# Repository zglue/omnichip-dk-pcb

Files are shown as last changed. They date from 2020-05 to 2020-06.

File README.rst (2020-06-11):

OmniChip Development Board PCB Design Files
*******************************************

.. _figure_ftdi_drivers:
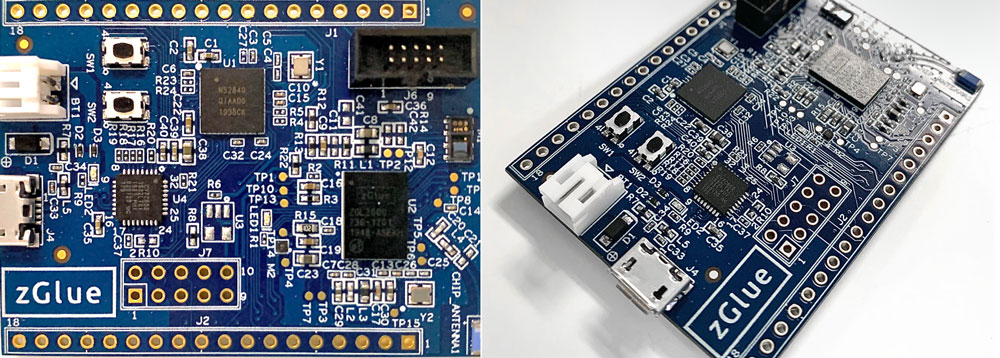
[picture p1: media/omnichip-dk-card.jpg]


Version: 1.0.0

Author(s): Jorge L. Rojas, Olivia Liao

zGlue Inc, 883 N Shoreline Blvd, C200, Mountain View, CA 94043, USA

Contact(s): jorge@zglue.com, olivia@zglue.com

*Released under zOH License v. 1.0 for open-source development*

Overview
========

`Click here to purchase an OmniChip development board <https://zglue.com/products/omnichip>`_

Want to explore zGlue's technology? Get familiar with the first active silicon interposer with the OmniChip development board. OmniChip is a full system on a chip built with this technology including: a Cortex-M4 MCU + BLE, a battery charger, a heart rate sensor, 3-axis accelerometer, 3-axis magnetometer, a temperature sensor, and a 32kHz TCXO. The hardware design files found in this repository are being released by zGlue Inc under the zGlue Open Hardware V1 license.

Make an account on zGlue's `ChipBuilder web tool <https://zglue.com/products/chipbuilder>`_, and visit the `OmniChip system design <https://chipbuilder.zglue.com/system/2647/physical/>`_ to modify the OmniChip design. With hardware at your fingertips, you can start programming your ZIP!

What's Included?
================

* OmniChip DK schematic design files
* OmniChip DK layout & gerber files
* zGlue Open Hardware License V1 (zOH V1 License)

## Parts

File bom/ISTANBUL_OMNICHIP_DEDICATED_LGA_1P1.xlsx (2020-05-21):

Item | Quantity | Quantity needed | Quantity ordered | Reference | Part | PCB Footprint | Manufacturer | Part Number | Distributor | Distributor Part Number
1 | 1 | 50 | 55 | BT1 | JST-2PIN-MALE | HDR1X2X2MM_S2B-PH-K-S | JST Sales America Inc. | S2B-PH-K-S(LF)(SN) | Digikey | 455-1719-ND
2 | 1 | 50 | 60 | CHIP_ANTENNA1 | A0 | RFANT3216120A5T | Walsin Technology Corporation | RFANT3216120A5T | Digikey | 1292-1000-1-ND
3 | 6 | 300 | 500 | C1,C2,C12,C17,C35,C36 | 1 uF | 402 | Samsung Electro-Mechanics | CL05A105MP5NNNC | Digikey | 1276-1448-1-ND
4 | 9 | 450 | 600 | C3,C6,C7,C18,C24,C28,C31,C32,C34 | 0.1 uF | 201 | Murata Electronics | GRM033R61A104ME15D | DigiKey | 490-5405-1-ND
5 | 4 | 200 | 300 | C4,C5,C25,C26 | 8 pF | 201 | Murata Electronics | GRM0335C1H8R0DA01J | DigiKey | 490-13331-1-ND
6 | 3 | 150 | 250 | C8,C23,C38 | 10 uF | 603 | Taiyo Yuden | LMK107BBJ106MALT | DigiKey | 587-3258-1-ND
7 | 4 | 200 | 300 | C9,C16,C19,C22 | 4.7 uF | 402 | Murata Electronics | GRM155R61A475MEAAD | DigiKey | 490-14306-1-ND
8 | 3 | 150 | 250 | C10,C13,C14 | 0.1 nF | 201 | Murata Electronics | GRM033R71C101KA01D | DigiKey | 490-6146-1-ND
9 | 1 |  |  | C11 | DNP | 402
10 | 1 | 50 | 100 | C15 | 820 pF | 201 | Murata Electronics | GRM033R71E821KA01D | DigiKey | 490-3183-1-ND
11 | 1 | 50 | 100 | C20 | 0.8pF | 402 | Walsin Technology Corporation | 0402N0R8B500CT | Digikey | 1292-1236-1-ND
12 | 1 | - | - | C21 | DNP | 402
13 | 1 | - | - | C27 | DNP | 201
14 | 3 | 150 | 200 | C29,C30,C40 | 2.2 uF | 402 | Taiyo Yuden | LMK105BJ225MV-F | DigiKey | 587-3153-1-ND
15 | 1 | 50 | 100 | C33 | 10 nF | 201 | Murata Electronics | GRM033R71E103KE14D | DigiKey | 490-14454-1-ND
16 | 1 | - | - | C37 | DNP | 201
17 | 1 | 50 | 100 | C39 | 0.1 uF | 402 | Taiyo Yuden | EMK105BJ105KV-F | DigiKey | 587-2477-1-ND
18 | 1 | - | - | C41 | DNP | 603
19 | 1 | - | - | C42 | DNP | 402
20 | 1 | 50 | 100 | D1 | MMSZ5231B-7-F | SOD123 | Diodes Incorporated | MMSZ5231B-7-F | Digikey | MMSZ5231B-FDICT-ND
21 | 2 | 100 | 150 | D2,D3 | PDIODE | SOD923 | ON Semiconductor | NSR0620P2T5G | Digikey | NSR0620P2T5GOSCT-ND
22 | 2 | 100 |  | J1,J2 | DNP |  | Adam Tech | PH1-12-UA | Digikey
23 | 1 | 50 | 55 | J4 | USB MICRO | usb_micro-b | Amphenol FCI | 10118193-0001LF | Digikey | 609-4616-1-ND
24 | 1 | 50 | 55 | J6 | HDR 5x2 | CNC_3220-10-0100-00 | CNC Tech |  | Digikey | 1175-1627-ND
25 | 1 | - | - | J7 | DNP
26 | 2 | 100 | 150 | LED1,LED2 | RED | sml-p12-p13x | Rohm Semiconductor | SML-P12U2TT86R | Digikey | 846-1192-1-ND
27 | 1 | 50 | 100 | L1 | 2.2 uH | 603 | TDK Corporation | MLZ1608N2R2LT000 | Digikey | 445-6754-1-ND
28 | 1 | 50 | 100 | L2 | 15 nH | 402 | Taiyo Yuden | HK100515NJ-T | Digikey | 587-1521-1-ND
29 | 1 | 50 | 100 | L3 | 10 uH | 603 | TDK Corporation | MLZ1608N100LT000 | Digikey | 445-6755-1-ND
30 | 1 | 50 | 100 | L4 | 3.9 nH | 402 | Taiyo Yuden | HK10053N9S-T | Digikey | 587-1509-1-ND
31 | 1 | 50 | 100 | L5 | 120R/0.55A | 402 | TDK Corporation | MMZ1005S121CT000‎ | Digikey | 445-2160-1-ND‎
32 | 1 | 50 | 55 | M1 | SFH7050 | SFH_7050 | OSRAM Opto Semiconductors Inc. | SFH 7050 | Digikey | 475-3346-1-ND
33 | 1 | 50 | 100 | M2 | UHD1110-FKA-CL1A13R3Q1BBQFMF3 |  | Cree Inc. | UHD1110-FKA-CL1A13R3Q1BBQFMF3 | Digikey | UHD1110-FKA-CL1A13R3Q1BBQFMF3CT-ND
34 | 2 | 100 | 150 | R1,R9 | 402 | 201 | Yageo | RC0201FR-07402RL | Digikey | YAG2658CT-ND
35 | 3 | - | - | R2,R23,R24 | DNP | 201
36 | 2 | 100 | 150 | R3,R8 | 1000 | 402 | Yageo | RC0402FR-071KL | Digikey | 311-1.00KLRCT-ND
37 | 2 | - | - | R4,R5 | DNP | 201
38 | 1 | 50 | 100 | R6 | 499k | 201 | Yageo | ?RC0201FR-07499KL? | Digikey | ?YAG2699CT-ND?
39 | 3 | 150 | 250 | R7,R11,R22 | 0 | 402 | Yageo | RC0402JR-070RL | Digikey | 311-0.0JRCT-ND
40 | 1 | - | - | R10 | DNP | 402
41 | 1 | 50 | 100 | R12 | 14.3K | 402 | Panasonic Electronic Components | ERJ-2RKF1432X | Digikey | P14.3KLCT-ND
42 | 1 | 50 | 100 | R13 | 14K | 402 | Yageo | RC0402FR-0714KL | Digikey | 311-14.0KLRCT-ND
43 | 1 | - | - | R14 | DNP | 402
44 | 1 | 50 | 100 | R15 | 1000 | 603 | Yageo | RC0603JR-071KL | Digikey | 311-1.0KGRCT-ND
45 | 6 | 300 | 400 | R16,R17,R18,R19,R20,R21 | 22 | 201 | Stackpole Electronics Inc | RMCF0201FT22R0 | Digikey | RMCF0201FT22R0CT-ND
46 | 2 | 100 | 110 | SW1,SW2 | KMR221GLFS |  | C&K | KMR221GLFS | Digikey | 401-1427-6-ND
47 | 15 | 750 |  | TP1,TP2,TP3,TP4,TP5,TP6,TP7,TP8,TP9,TP10,TP11,TP12,TP13,TP14,TP15 | TP_MINITURE | tp_smd35r
48 | 1 | 50 | 55 | U1 | NRF52840 | AQFN73_7x7mm_p5mm_ep | Nordic | NRF52840-QIAA-R | DigiKey | 1490-1071-1-ND
49 | 1 | 50 |  | U2 | OmniChip
50 | 1 | 50 | 55 | U3 | DNP
51 | 1 | 50 | 55 | U4 | CY7C65215 |  | Cypress | CY7C65215-32LTXI | Digikey | CY7C65215-32LTXI-ND
52 | 2 | 100 | 110 | Y1,Y2 | Crystal | xtal_2mmx1p6mm | EPSON | FA-128 32.0000MF10Z-AJ3 | Mouser | 732-FA12832.F10Z-AJ3

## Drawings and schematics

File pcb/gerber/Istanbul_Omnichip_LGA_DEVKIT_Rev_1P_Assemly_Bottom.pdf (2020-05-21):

# ART FILM - ASSY-BOT

# LAYER:ASSEMBLY BOTTOM

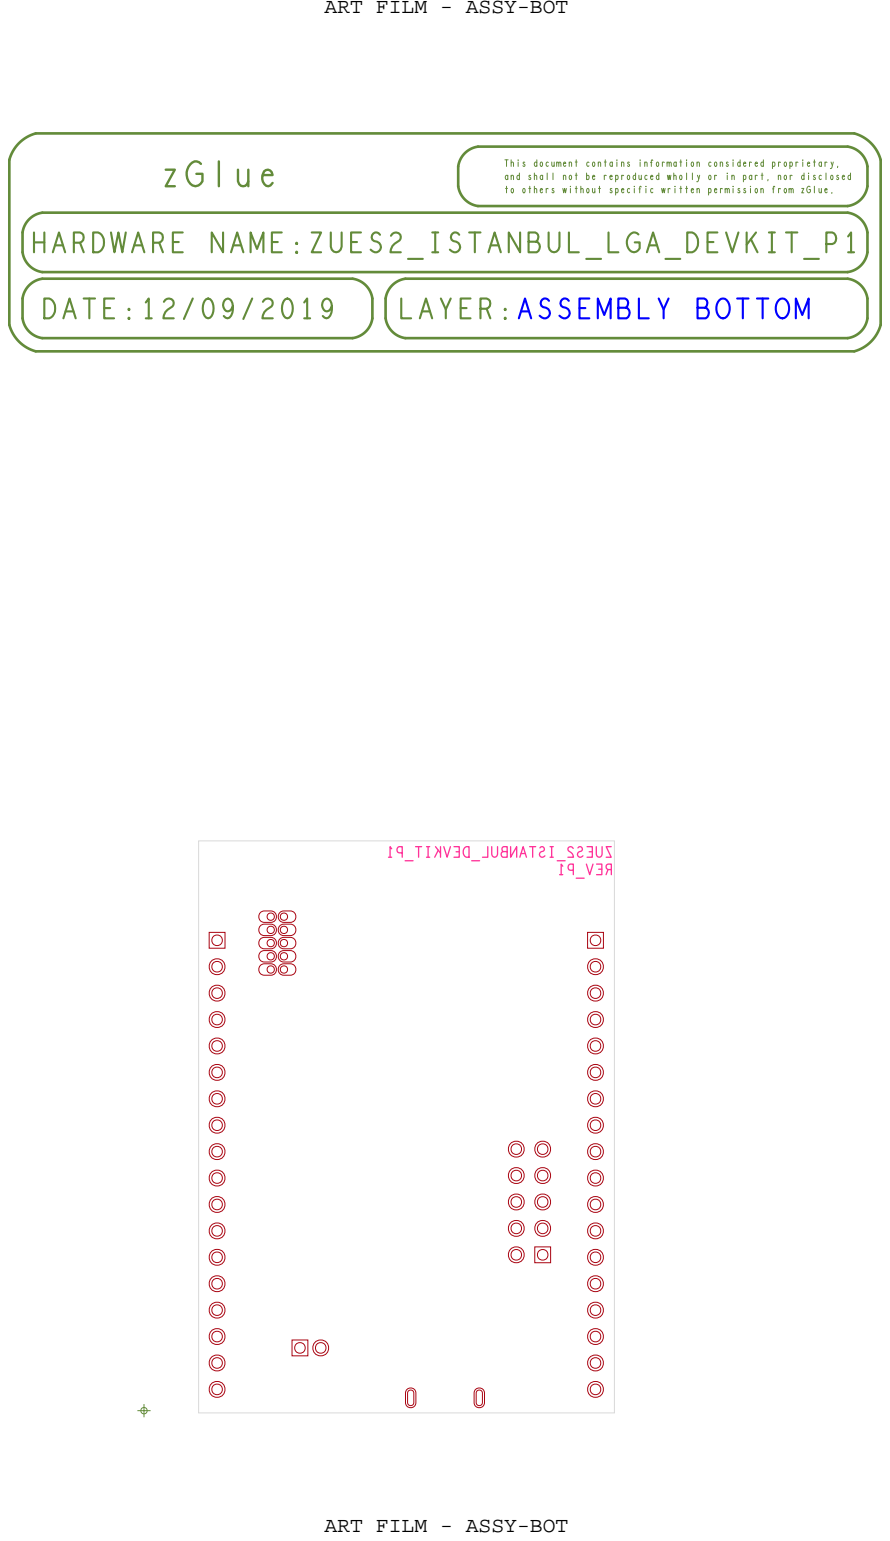
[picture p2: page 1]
zGlue; HARDWARE NAME:ZUES2_ISTANBUL_LGA_DEVKIT_P1; DATE:12/09/2019

This document contains information considered proprietary,
and shall not be reproduced wholly or in part, nor disclosed
to others without specific written permission from zGlue.

ART FILM - ASSY-BOT

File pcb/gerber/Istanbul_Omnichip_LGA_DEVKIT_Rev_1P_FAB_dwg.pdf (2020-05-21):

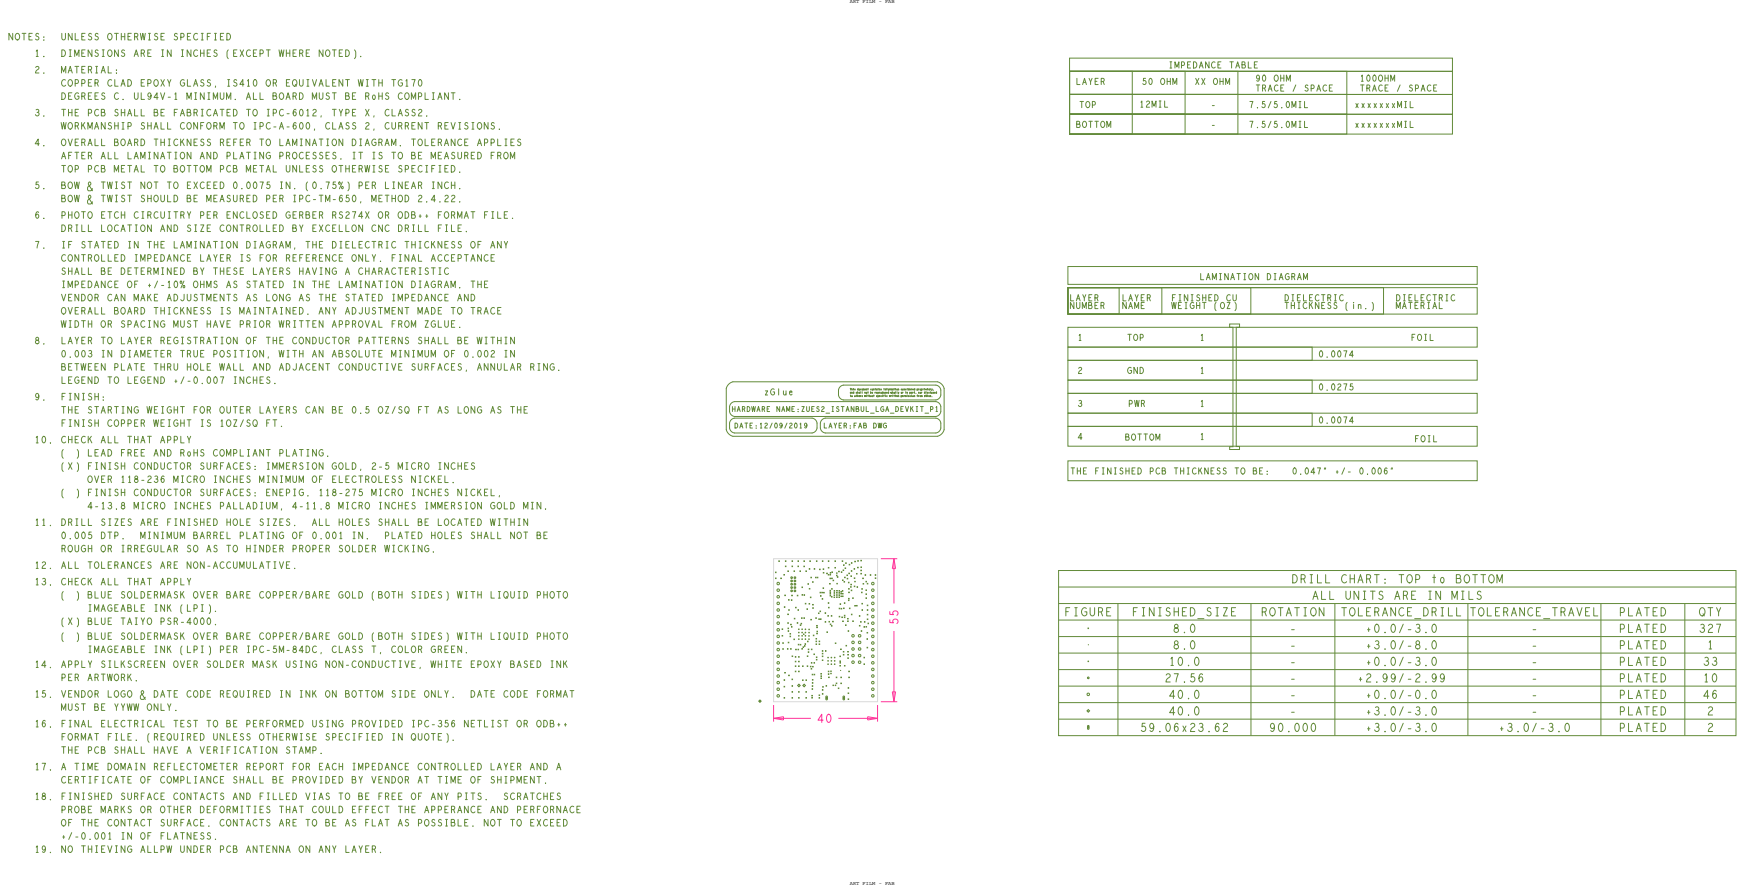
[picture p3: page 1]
QTY; PLATED; TOLERANCE_TRAVEL; MATERIAL; DIELECTRIC; FOIL; TRACE / SPACE; 100OHM; xxxxxxxMIL; 90 OHM; 7.5/5.0MIL; THICKNESS (in.); ROTATION; 50 OHM; IMPEDANCE TABLE; XX OHM; 12MIL; WEIGHT (OZ); FINISHED CU; LAMINATION DIAGRAM; FINISHED_SIZE; LAYER; BOTTOM; TOP; NUMBER; NAME; PWR; GND; THE FINISHED PCB THICKNESS; FIGURE; zGlue; HARDWARE NAME:ZUES2_ISTANBUL_LGA_DEVKIT_P1; DATE:12/09/2019; 1. DIMENSIONS ARE IN; INCHES (EXCEPT WHERE NOTED).; COPPER CLAD EPOXY GLASS,; IS410 OR EQUIVALENT WITH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

ART FILM - FAB

NOTES: UNLESS OTHERWISE SPECIFIED
2. MATERIAL:
DEGREES C. UL94V-1 MINIMUM. ALL BOARD MUST BE RoHS COMPLIANT.
6. PHOTO ETCH CIRCUITRY PER ENCLOSED GERBER RS274X OR ODB++ FORMAT FILE.
DRILL LOCATION AND SIZE CONTROLLED BY EXCELLON CNC DRILL FILE.
LEGEND TO LEGEND +/-0.007 INCHES.
9. FINISH:

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

FINISH COPPER WEIGHT IS 1OZ/SQ FT.
10. CHECK ALL THAT APPLY
( ) LEAD FREE AND RoHS COMPLIANT PLATING.

LAYER:FAB DWG

12. ALL TOLERANCES ARE NON-ACCUMULATIVE.
13. CHECK ALL THAT APPLY
IMAGEABLE INK (LPI).
(X) BLUE TAIYO PSR-4000.

DRILL CHART: TOP to BOTTOM
ALL UNITS ARE IN MILS
TOLERANCE_DRILL

PER ARTWORK.
MUST BE YYWW ONLY.
PROBE MARKS OR OTHER DEFORMITIES THAT COULD EFFECT THE APPERANCE AND PERFORNACE
+/-0.001 IN OF FLATNESS.
19. NO THIEVING ALLPW UNDER PCB ANTENNA ON ANY LAYER.

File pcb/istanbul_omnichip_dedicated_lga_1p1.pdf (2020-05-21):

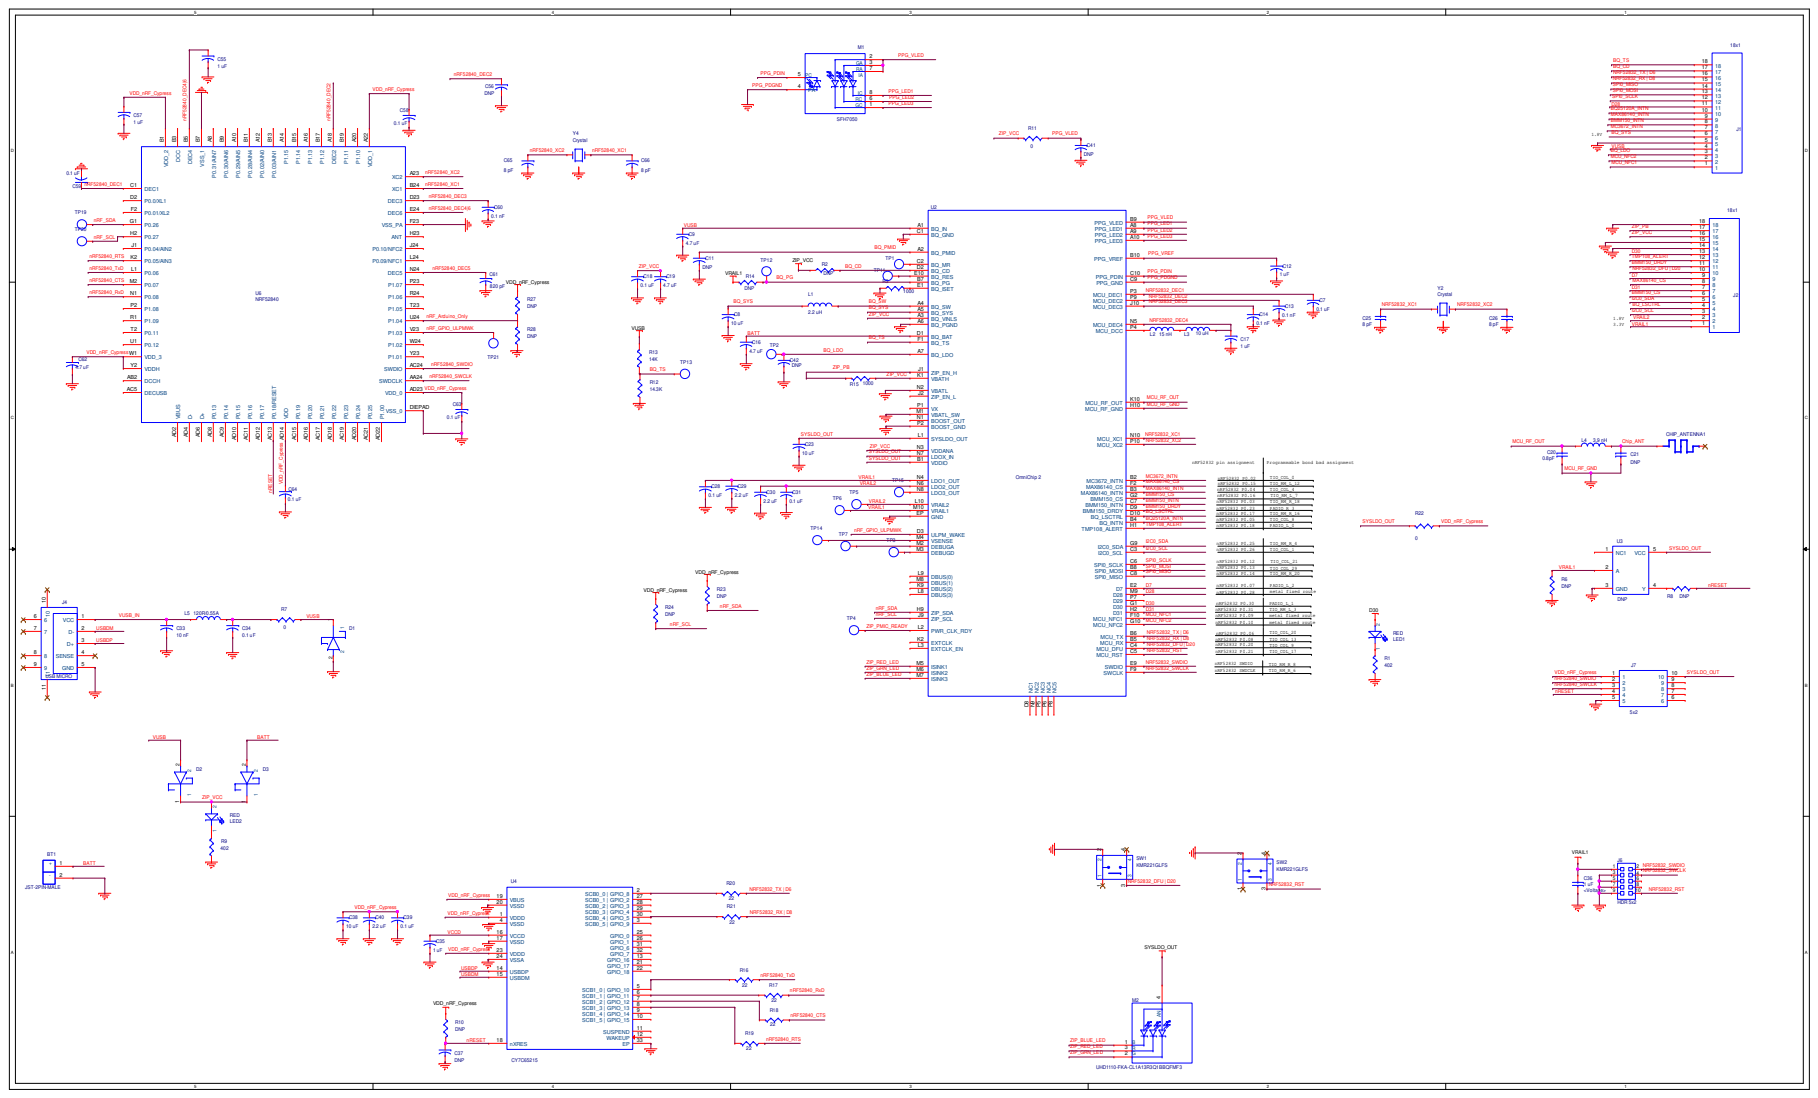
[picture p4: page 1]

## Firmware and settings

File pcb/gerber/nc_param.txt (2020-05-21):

INTEGER-PLACES         2
DECIMAL-PLACES         5
X-OFFSET               0.000000
Y-OFFSET               0.000000
FEEDRATE               1
COORDINATES            ABSOLUTE
OUTPUT-UNITS           ENGLISH
TOOL-ORDER             INCREASING
REPEAT-CODES           YES
SUPPRESS-LEAD-ZEROES   NO
SUPPRESS-TRAIL-ZEROES  NO
SUPPRESS-EQUAL         NO
TOOL-SELECT            NO
OPTIMIZE_DRILLING      NO
ENHANCED_EXCELLON      YES
HEADER                 none
LEADER                 12
CODE                   ASCII
SEPARATE               NO
SEPARATE-ROUTING       NO
DRILLING               LAYER-PAIR
BACKDRILL              NO
CAVITY                 NO
COUNTER                NO
TOLERANCE_DRILL        YES
TOLERANCE_TRAVEL       YES
TOOL_SIZE              YES
ROTATION               YES
NON_STANDARD           YES
TOTAL_DRILL            NO
SEPARATE_SLOT          NO
SUPPRESS_TOLERANCE     YES
SUPPRESS_TOOLSIZE      YES
SUPPRESS_ROTATION      YES

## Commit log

2020-05-21 Changing BOM revision
    [ISTANBUL_OMNICHIP_DEDICATED_LGA_1P1.xlsx]
2020-06-10 Updating revision
    [Istanbul_Omnichip_LGA_DEVKIT_Rev_1P1.brd]
